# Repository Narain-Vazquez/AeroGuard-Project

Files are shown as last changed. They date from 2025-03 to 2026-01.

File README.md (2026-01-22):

# UIC Senior Design Project 

### PCB Design Contributors:

Narain Vazquez  
Nico Gomez

### Repository Description:

This repository specifically holds the contents of the electrical portion of the Aeroguard Project, including the schematics for our PCB design, power distribution, and system integration.  

All included files are designed to work specifically with **KiCad**, and the project files created for this project can be found in the following directories:  

- `libraries_v4` – contains custom KiCad libraries created for the project.  
- `rpi-aeroguard-template_v4` – contains the KiCad project files and PCB templates for the Aeroguard design.

### Aeroguard Description & Demo:

The Aeroguard Project is a senior design initiative focused on developing an autonomous aerial monitoring system. The system runs on a Linux-based platform and leverages YOLOv11 for real-time detection of fires, smoke, and safety equipment protocol. Video is streamed over RTMP, and the system can trigger alerts using speakers and lights to notify personnel of hazards or protocol violations.

The video demo showcases our Aeroguard prototype board in action. It demonstrates the fire detection feature, which triggers the speaker alerting system (note: the video itself has no audio).

Aeroguard Demo
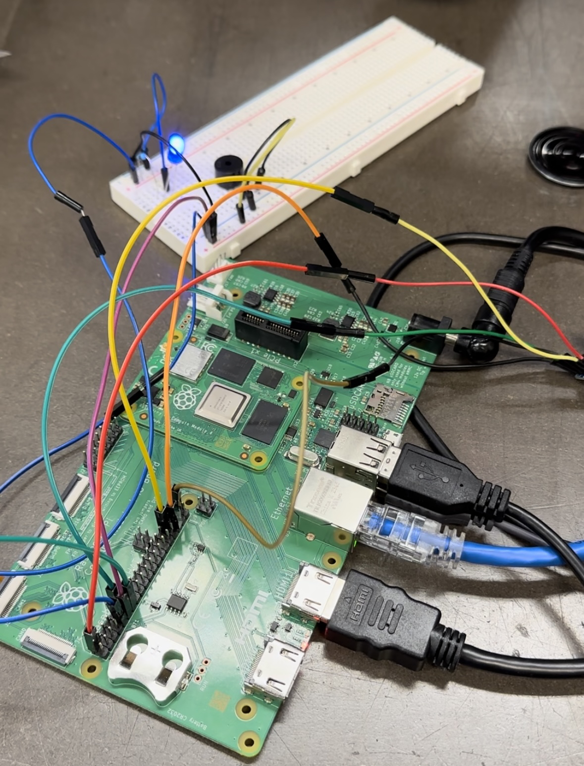
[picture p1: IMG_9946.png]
Prototype Board

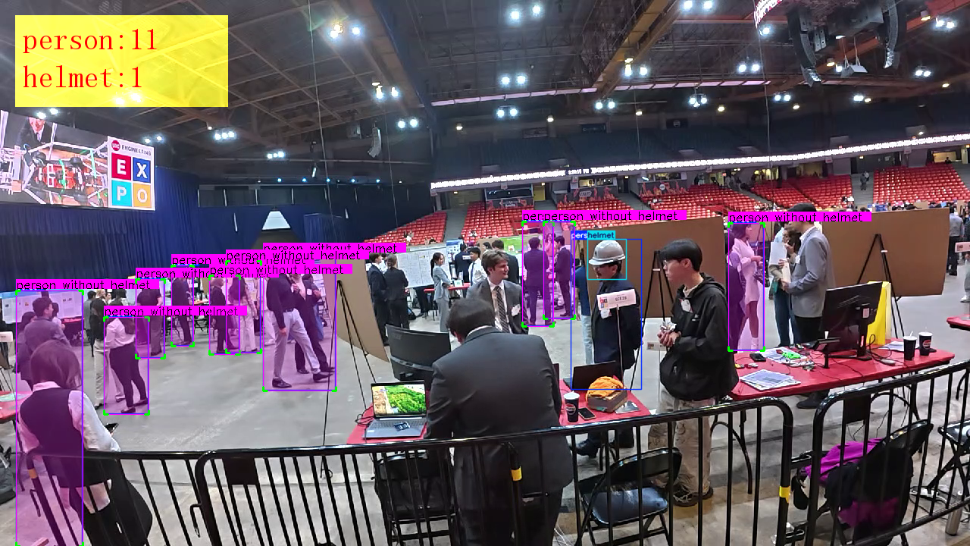
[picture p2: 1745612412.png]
Image Detection


### Raspberry Pi Compute Module 4 (CM4) Carrier Template
Rendered example of RPi CM4 Carrier Template PCB

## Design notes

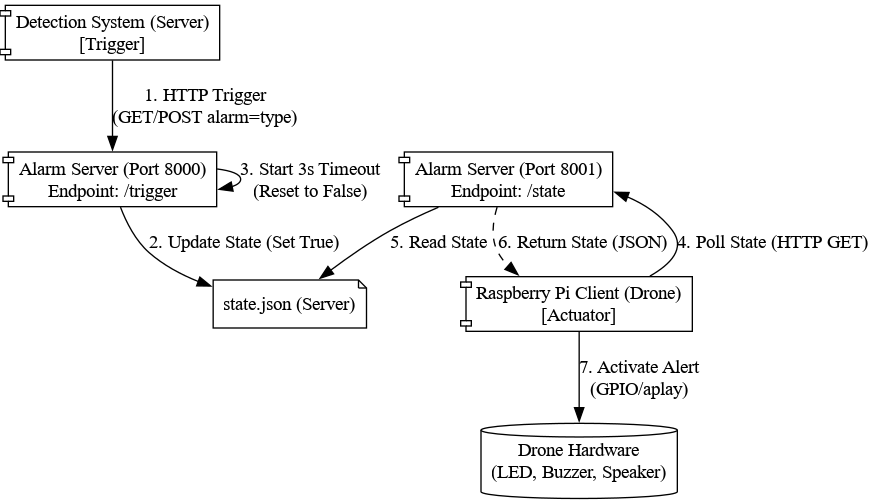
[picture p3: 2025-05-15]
Software/Software files/Flowcharts/Alarm System Architecture Diagram.png

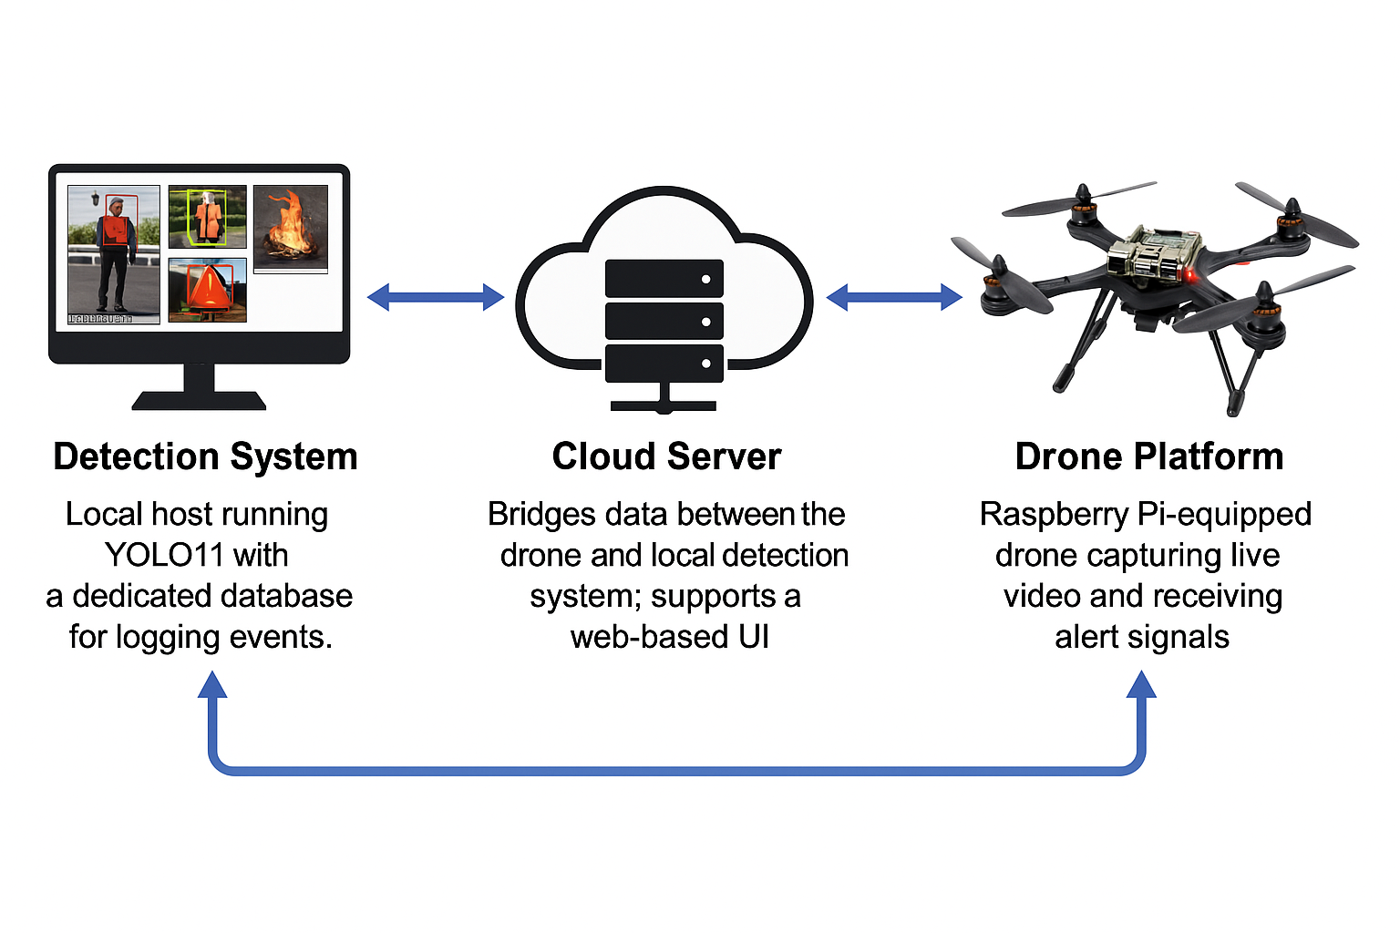
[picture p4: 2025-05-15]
Software/Software files/Flowcharts/AeroGuard System High-Level Architecture Block Diagram.png

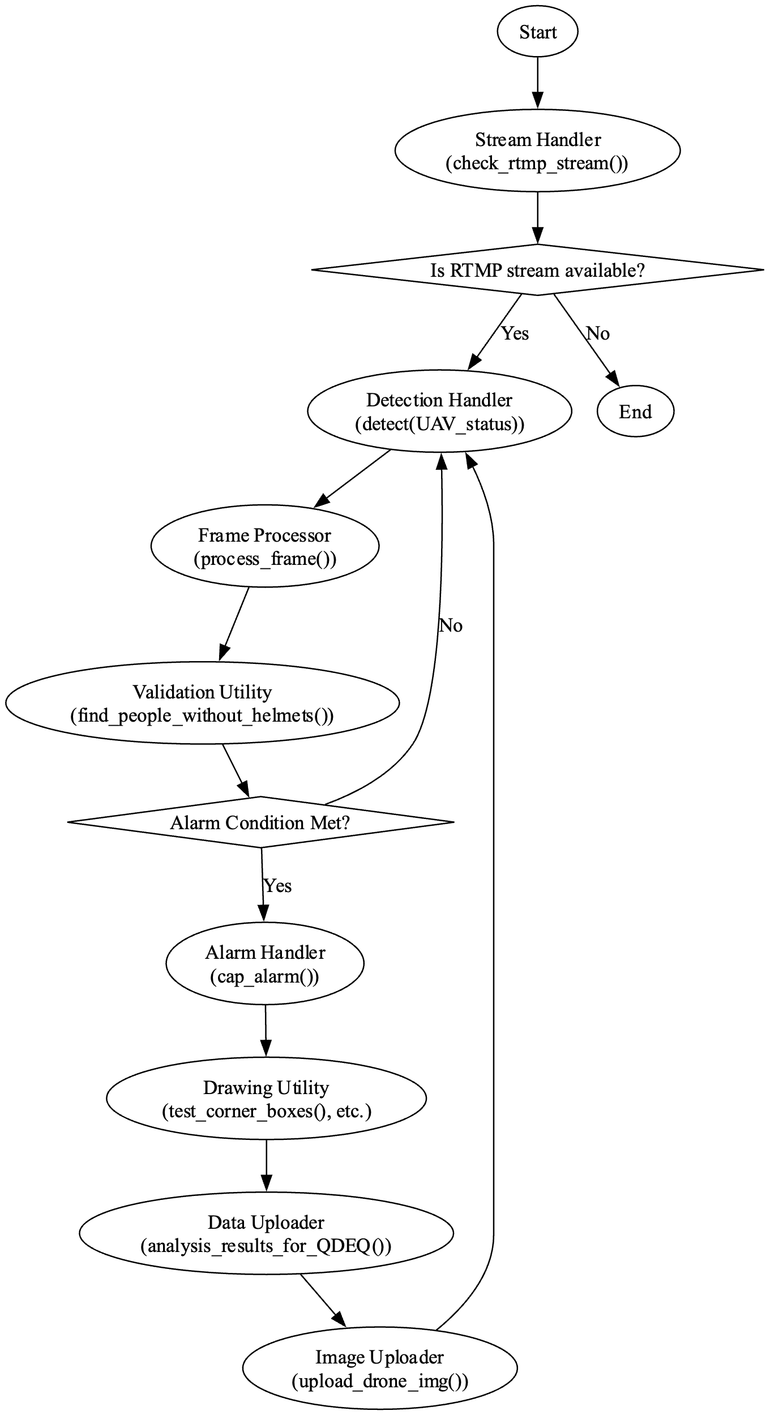
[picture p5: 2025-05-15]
Software/Software files/Flowcharts/high-level flowchart.png

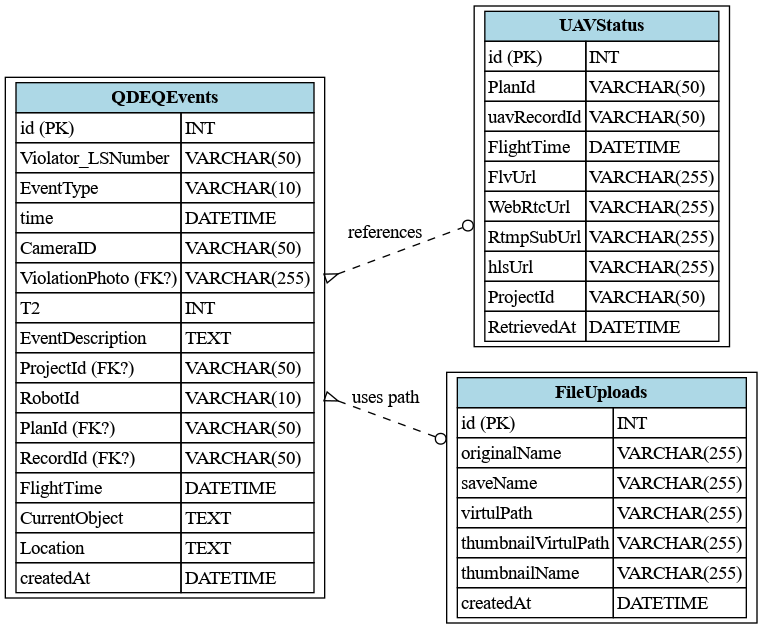
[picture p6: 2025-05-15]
Software/Software files/Flowcharts/Database Schema ERD.png

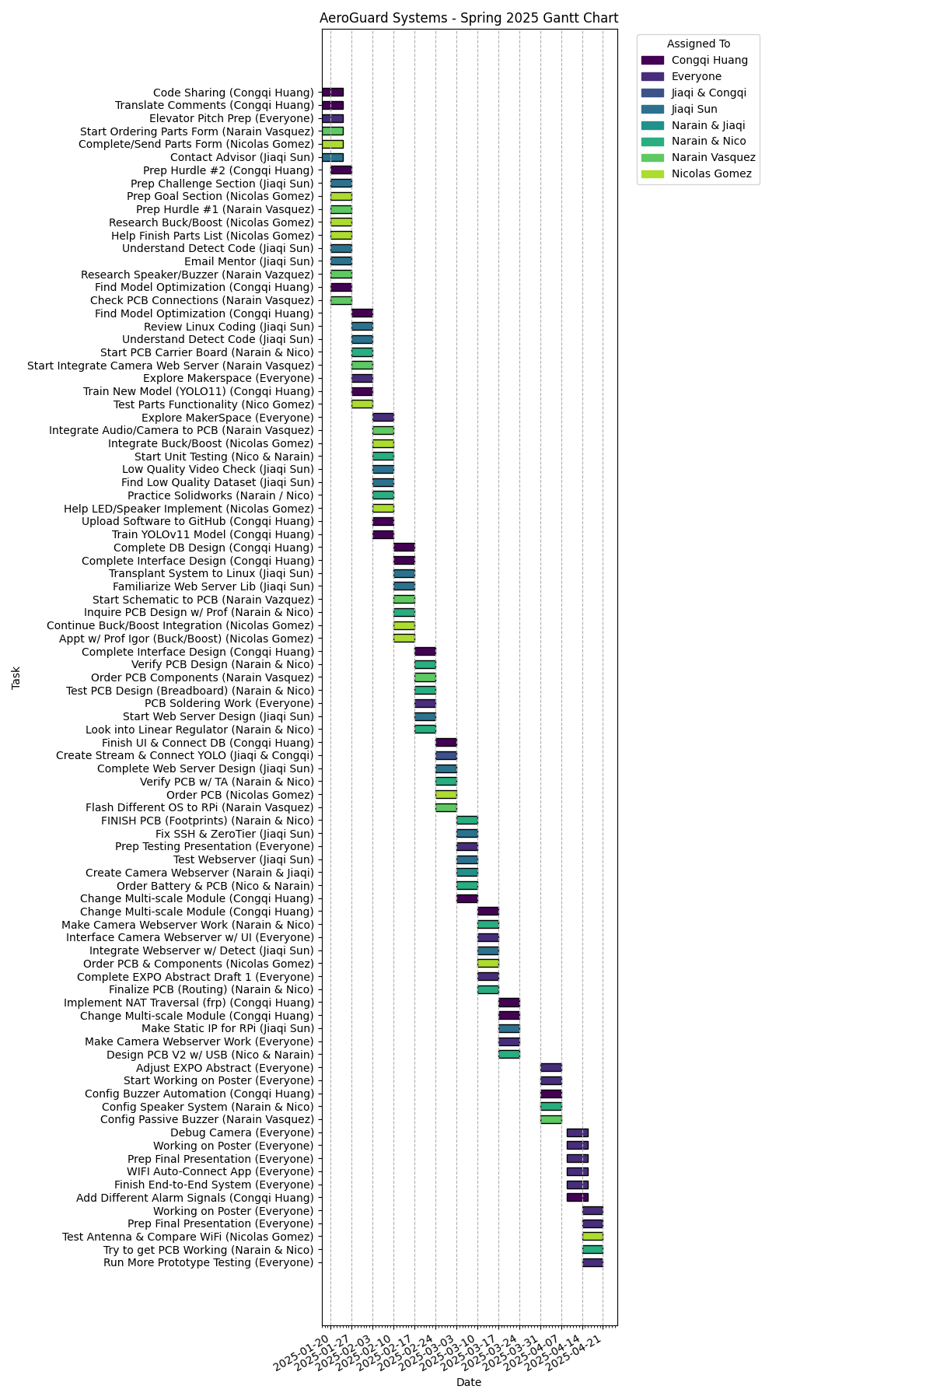
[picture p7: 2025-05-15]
Software/Software files/Flowcharts/Gantt Chart.png

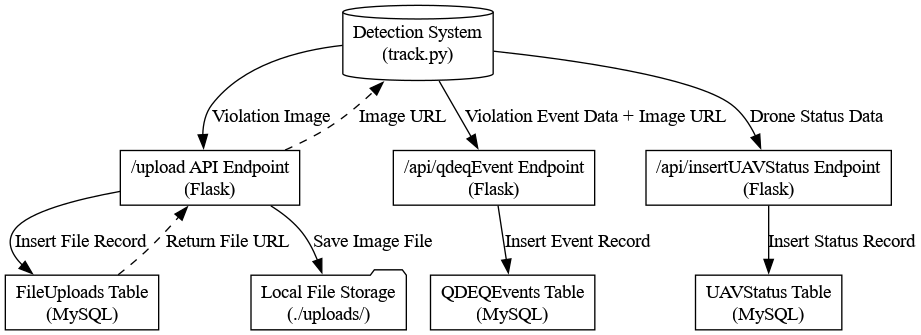
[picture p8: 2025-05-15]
Software/Software files/Flowcharts/Database Data Ingestion Flow Diagram.png

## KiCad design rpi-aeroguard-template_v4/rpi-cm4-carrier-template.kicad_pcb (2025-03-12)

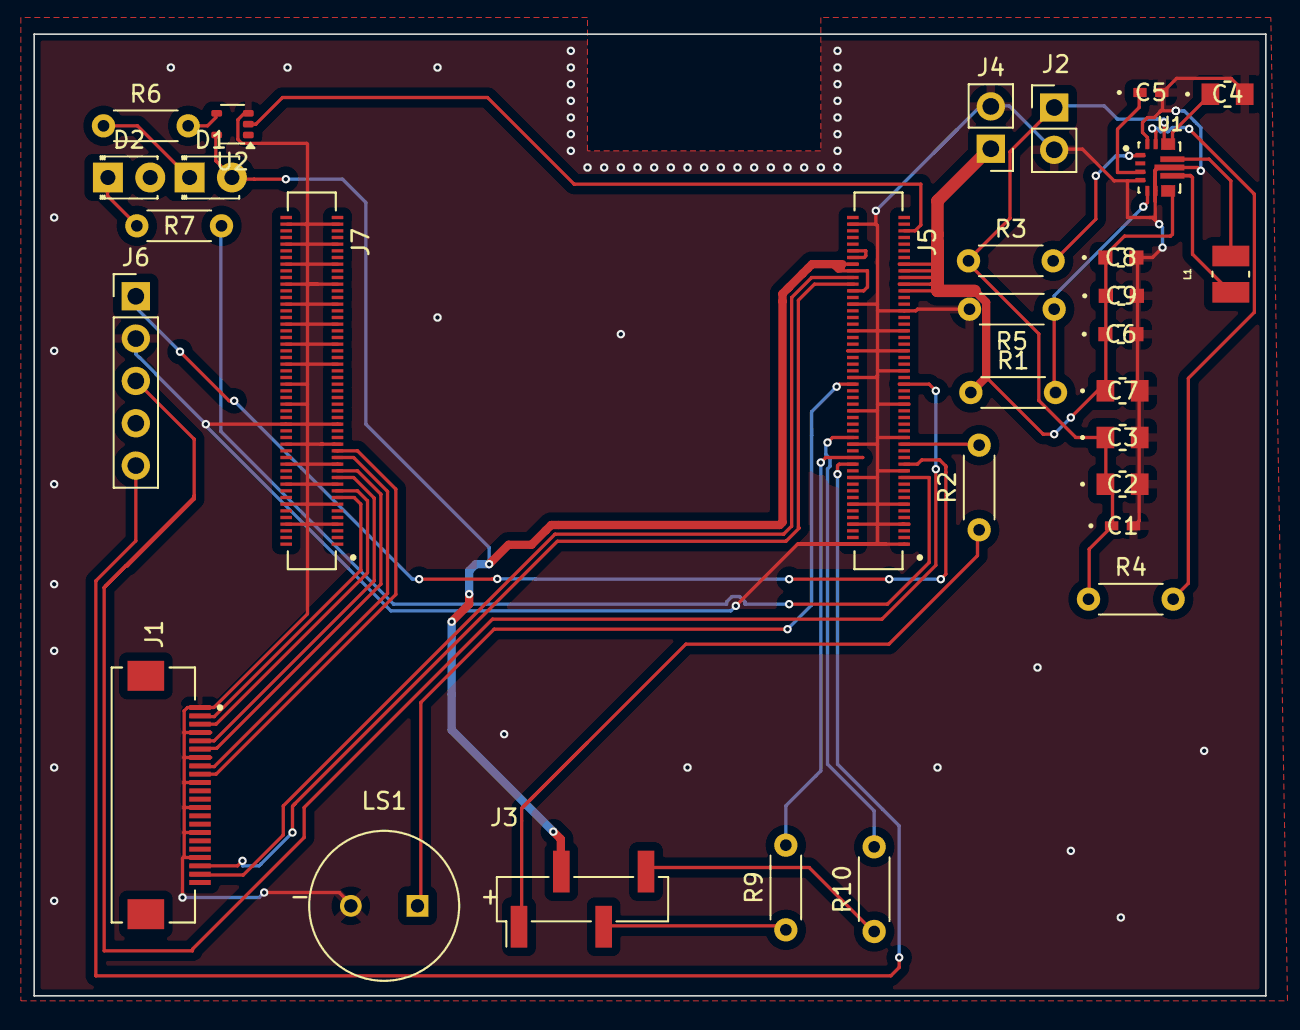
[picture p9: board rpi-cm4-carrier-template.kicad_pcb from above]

Board: 2 copper layers, 73.9 x 57.7 mm, 31 parts (0 on the bottom side), 34 nets.

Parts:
C1, C5: 0.1uF; CAP_CL05_SAM-M
C2, C3, C4, C7: 10uF; G-21_MUR-M
C6, C8, C9: 22uF; CAP_CL10_SAM-M
D1: LED Red; LED_D1.8mm_W3.3mm_H2.4mm
D2: LED Green; LED_D1.8mm_W3.3mm_H2.4mm
J1: F305-1A7H1-21022-E100; AMPHENOL_F305-1A7H1-21022-E100
J2, J4: Conn_01x02_Pin; PinHeader_1x02_P2.54mm_Vertical
J3: Conn_01x04_Pin; PinHeader_1x04_P2.54mm_Vertical_SMD_Pin1Left
J5, J7: DF40C-100DS-0.4V_51_; HIROSE_DF40C-100DS-0.4V_51_
J6: Conn_01x05_Pin; PinHeader_1x05_P2.54mm_Vertical
L1: 1.5uH; INDC2520X100N
LS1: CST-931AP; CUI_CST-931AP
R1: 365k; R_Axial_DIN0204_L3.6mm_D1.6mm_P5.08mm_Horizontal
R2, R9, R10: 220; R_Axial_DIN0204_L3.6mm_D1.6mm_P5.08mm_Horizontal
R3, R4: 10k; R_Axial_DIN0204_L3.6mm_D1.6mm_P5.08mm_Horizontal
R5: 68.1k; R_Axial_DIN0204_L3.6mm_D1.6mm_P5.08mm_Horizontal
R6, R7: 1k; R_Axial_DIN0204_L3.6mm_D1.6mm_P5.08mm_Horizontal
U1: TPS63070RNMR; VREG_TPS63070RNMR
U2: 74LVC1G07SE-7; SOT-353_SC-70-5

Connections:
+1.8V: J5.88, J5.90
+3.3V: D1.2 (A), J3.2, J5.78, J5.84, J5.86, U2.5 (VCC)
+5V: C6.1, C7.1, C8.1, C9.1, J4.1, J5.77, J5.79, J5.81, J5.83, J5.85, R1.1, U1.7_8 (VOUT)
/CM4 GPIO/GPIO17: J5.50, LS1.P
/CM4 GPIO/GPIO18: J5.49, J6.3
/CM4 GPIO/GPIO19: J5.26, J6.5
/CM4 GPIO/GPIO21: J5.25, J6.1
/CM4 GPIO/GPIO 5: J5.34, R10.2
/CM4 GPIO/GPIO 12: J5.31, R2.2
/CM4 GPIO/GPIO 13: J5.28, R9.2
/CM4 GPIO/PI_nLED_Activity: J5.21, R7.2
/CM4 GPIO/nPWR_LED: J5.95, U2.2
/CM4 High Speed/CAM0_C_N: J1.8, J7.27
/CM4 High Speed/CAM0_C_P: J1.9, J7.29
/CM4 High Speed/CAM0_D0_N: J1.2, J7.15
/CM4 High Speed/CAM0_D0_P: J1.3, J7.17
/CM4 High Speed/CAM0_D1_N: J1.5, J7.21
/CM4 High Speed/CAM0_D1_P: J1.6, J7.23
/CM4 High Speed/SCL1: J1.20, J5.80
/CM4 High Speed/SDA1: J1.21, J5.82
EN: R4.2, U1.14 (EN)
FB: R1.2, R5.1, U1.5 (FB)
GND: C1.2, C2.2, C3.2, C4.2, C5.2, C6.2, C7.2, C8.2, C9.2, J1.1, J1.4, J1.7, J1.10, J1.13, J1.16, J1.19, J2.2, J4.2, J5.1, J5.2, J5.7, J5.8, J5.13, J5.14, J5.22, J5.23, J5.32, J5.33, J5.42, J5.43, J5.52, J5.53, J5.59, J5.60, J5.65, J5.66, J5.71, J5.74, J5.98, J6.2, J7.7, J7.8, J7.13, J7.14, J7.19, J7.20, J7.25, J7.26, J7.31, J7.32, J7.37, J7.38, J7.44, J7.50, J7.55, J7.56, J7.61, J7.62, J7.67, J7.68, J7.73, J7.74, J7.79, J7.80, J7.85, J7.86, J7.91, J7.92, J7.97, J7.98, LS1.M, R5.2, U1.4 (GND), U1.6 (FB2), U1.10 (PGND), U1.15 (VSEL), U2.3 (GND)
unnamed: D1.1 (K), R6.1
unnamed: D2.1 (K), R7.1
unnamed: J3.1, R2.1
unnamed: J3.3, R9.1
unnamed: J3.4, R10.1
unnamed: R6.2, U2.4
unnamed: L1.1, U1.11 (L1)
unnamed: L1.2, U1.9 (L2)
unnamed: C5.1, U1.3 (VAUX)
PS: R3.2, U1.1 (PS/SYNC)
VIN: C1.1, C2.1, C3.1, C4.1, J2.1, R3.1, R4.1, U1.12_13 (VIN)

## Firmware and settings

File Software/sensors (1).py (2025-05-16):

import json
import time
import requests
import RPi.GPIO as GPIO
from gpiozero import PWMOutputDevice
from subprocess import call

# Function to play different types of alarms
def play_alarm(alarm_type):
    LED_PIN = 27
    GPIO.setmode(GPIO.BCM)
    GPIO.setup(LED_PIN, GPIO.OUT)
    GPIO.output(LED_PIN, GPIO.HIGH)

    buzzer = PWMOutputDevice(17)
    buzzer.frequency = 1000
    buzzer.value = 0.5

    if alarm_type == "helmet":
        call(["aplay", "/home/aeroguard/Desktop/helmet_alarm.wav"])
    elif alarm_type == "lifejacket":
        call(["aplay", "/home/aeroguard/Desktop/lifejacket_alarm.wav"])
    elif alarm_type == "fire":
        call(["aplay", "/home/aeroguard/Desktop/fire_alarm.wav"])

    # Let the alarm sound for 1 second
    time.sleep(1)

    # Turn everything off
    buzzer.value = 0
    GPIO.output(LED_PIN, GPIO.LOW)
    GPIO.cleanup()

# Continuously monitor the remote state
while True:
    try:
        resp = requests.get("http://154.201.89.38:8001/state", timeout=5)
        data = resp.json()
        raw_state = data.get("state")
        if not raw_state:
            print("No 'state' field in response:", data)
        else:
            # Parse the JSON string into a dict
            state = json.loads(raw_state)
            #print("state is:", state)

            # Normalize to lowercase strings for comparison
            helmet = str(state.get("helmet", "")).lower()
            lifejacket = str(state.get("lifejacket", "")).lower()
            fire = str(state.get("fire", "")).lower()

            if helmet == "true":
                #print("Helmet not detected. Triggering alarm...")
                play_alarm("helmet")
            elif lifejacket == "true":
                #print("Lifejacket not detected. Triggering alarm...")
                play_alarm("lifejacket")
            elif fire == "true":
                #print("Fire detected. Triggering alarm...")
                play_alarm("fire")
            else:
                print("All clear. No alarm needed.")

    except Exception as e:
        print("Error occurred while requesting or processing state:", e)

    time.sleep(2)

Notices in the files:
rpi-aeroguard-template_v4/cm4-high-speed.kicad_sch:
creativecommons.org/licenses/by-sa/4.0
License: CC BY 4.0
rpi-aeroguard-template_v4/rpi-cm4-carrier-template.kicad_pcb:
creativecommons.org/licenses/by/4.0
